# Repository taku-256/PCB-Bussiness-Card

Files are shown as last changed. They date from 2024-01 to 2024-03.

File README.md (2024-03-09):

# WS2812B with PIC Microcontroller
created by taku-256 @taku_8bits

PICマイコンでNeoPixcelライブラリなしでWS2812Bの制御をする基板です。
高専ロボコン2023用に作成したものを改良しました。

2024年3月現在、部内ロボコンの回路、制御のワンオペ作業に追われているためDCDCを実装した際の動作確認ができていません。
それを除いた動作は確認しておりますので、ぜひ実際に実装して遊んでいただけると嬉しいです。

使用したマイコンはPIC18F26Q84で10MHzの水晶発振子をつけて動かしています。
この基板はこのマイコンの評価基板としても使えるようにピンヘッダーをつけられるようになっているのでPICマイコンに触れてみたい人は是非使ってみてください。

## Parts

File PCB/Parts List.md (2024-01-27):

# Parts List

| Part | Value or name(URL : 秋月電商/千石電商)|
|:----|----:|
| C1,2 | [100μF](https://akizukidenshi.com/catalog/g/g117877/) |
| C3 | [0.1μF](https://akizukidenshi.com/catalog/g/g100090/) |
| C4,5 | [33pF](https://akizukidenshi.com/catalog/g/g105109/) |
| C6,7 | [0.1μF(1608)](https://akizukidenshi.com/catalog/g/g113374/) |
| R1 | [330Ω(3216)](https://www.sengoku.co.jp/mod/sgk_cart/detail.php?code=EEHD-0CPK) |
| R2 | [1kΩ(2012)](https://akizukidenshi.com/catalog/g/g111796/) |
| R3,4 | [10kΩ(2012)](https://akizukidenshi.com/catalog/g/g111797/) |
| R5 | [200Ω(3216)](https://www.sengoku.co.jp/mod/sgk_cart/detail.php?code=EEHD-0ECC) |
| D1 | [LED(0603)](https://akizukidenshi.com/catalog/g/g109640/) |
| LED1,2 | [WS2812B](https://akizukidenshi.com/catalog/g/g107915/) |
| S1,2 | [トグルスイッチ](https://akizukidenshi.com/catalog/g/g100300/) |
| S3 | [タクトスイッチ](https://akizukidenshi.com/catalog/g/g103648/) |
| J1 | [Type-Cコネクタ](https://akizukidenshi.com/catalog/g/g116895/) |
| JP1,2 | [ピンソケット 1×42](https://akizukidenshi.com/catalog/g/g105779/) |
| JP3,4 | [NHコネクタ 3P L字](https://akizukidenshi.com/catalog/g/g114418/) |
| PICKIT | [L字ピンヘッダ 1×10](https://akizukidenshi.com/catalog/g/g106362/) |
| Q1 | [10MHz](https://akizukidenshi.com/catalog/g/g108668/) |
| PS1 | [OKL-T_6-W12N-C](https://akizukidenshi.com/catalog/g/g106187/) |
| U$1 | [VHコネクタ 2P](https://akizukidenshi.com/catalog/g/g112815/) |
| U$2 | [PIC18F26Q84](https://akizukidenshi.com/catalog/g/g116448/) |

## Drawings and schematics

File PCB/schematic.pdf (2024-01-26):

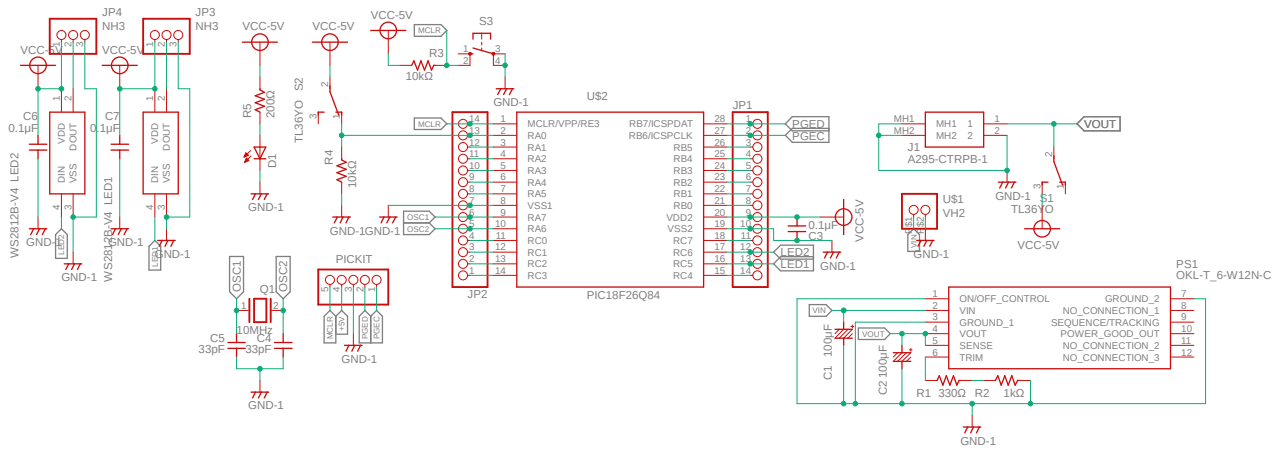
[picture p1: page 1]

13 | | RA0 2
12 | | RA1 3

10
11 12

VIN 2
GROUND_1 3
VOUT 4 SENSE 5

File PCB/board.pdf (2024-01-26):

## MODEPOWER

# taku_256

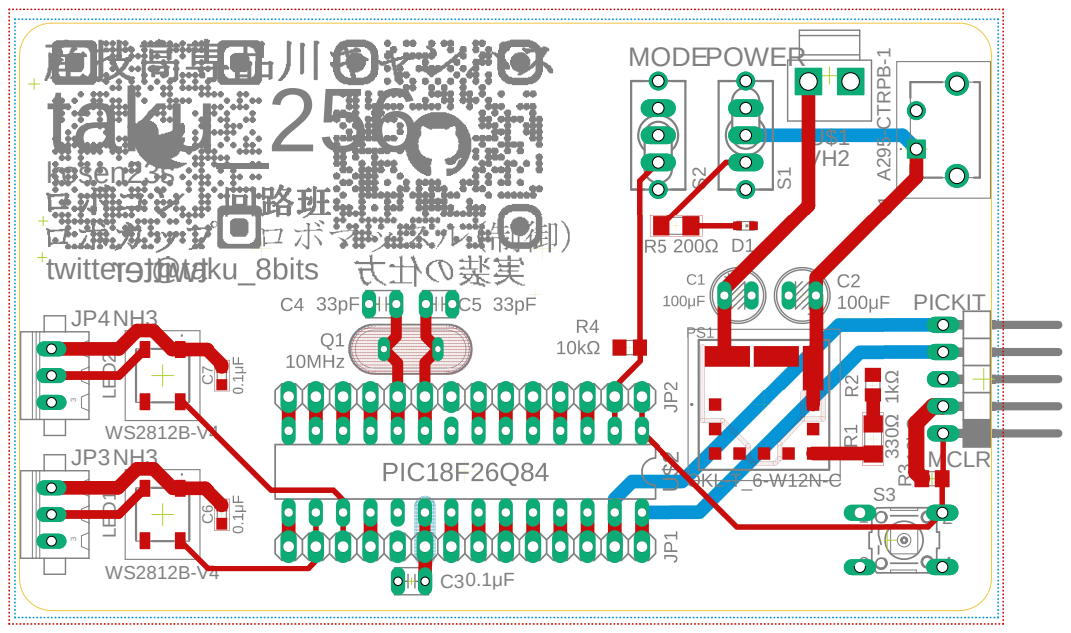
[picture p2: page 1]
kosen23s; twitter : @taku_8bits; MCLR; J1 A²⁹⁵⁻CTRPB⁻¹; PICKIT R³¹⁰k; S2 LED2; WS2812B-V4 LED¹

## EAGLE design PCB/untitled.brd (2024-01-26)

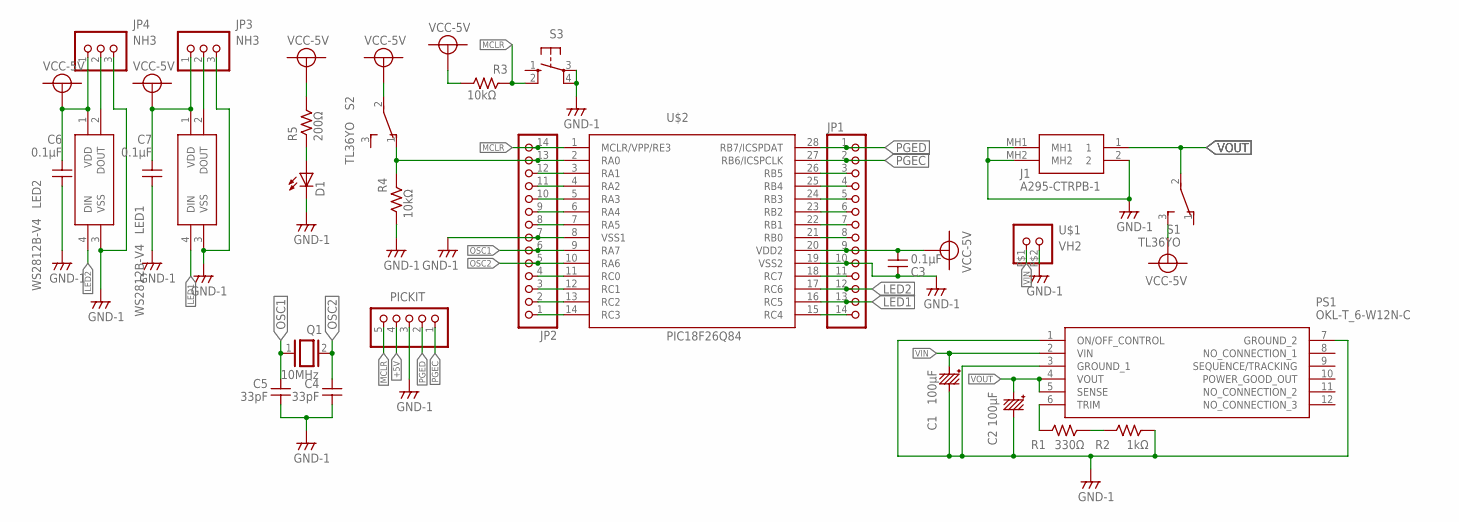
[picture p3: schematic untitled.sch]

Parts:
C1, C2: 100μF; CC:3
C3: 0.1μF; C:1
C4, C5: 33pF; C:1
C6, C7: 0.1μF; C1608
D1: LED""""; CHIPLED_0603
J1: A295-CTRPB-1; A295CTRPB1
JP1, JP2: PINHD-1X14; 1X14
JP3, JP4: NH3
LED1, LED2: WS2812B-V4; WS2812BV4
PICKIT: PINHD-1X5/90; 1X05/90
PS1: OKL-T_6-W12N-C; OKLT6W12NC
Q1: 10MHz; QS
R1: 330Ω; C3216
R2: 1kΩ; 2012
R3, R4: 10kΩ; 2012
R5: 200Ω; C3216
S1, S2: TL36YO; TL3XYO
S3: 10-XX; B3F-10XX
U$1: VH2
U$2: PIC18F26Q84; DIL28-3

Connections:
+5V: C3.P$1, C6.2, C7.2, JP1.9, JP3.1, JP4.1, LED1.1 (VDD), LED2.1 (VDD), PICKIT.4, R3.1, R5.2, S1.3 (S), S2.2, U$2.20 (VDD2)
GND: C1.- (P$2-), C2.- (P$2-), C3.P$2, C4.P$1, C5.P$1, C6.1, C7.1, D1.C, J1.2, J1.MH1, J1.MH2, JP1.10, JP2.7, JP3.3, JP4.3, LED1.3 (VSS), LED2.3 (VSS), PICKIT.3, PS1.1 (ON/OFF_CONTROL), PS1.3 (GROUND_1), PS1.7 (GROUND_2), R2.2, R4.1, S3.3, S3.4 (P1), U$1.P$2, U$2.8 (VSS1), U$2.19 (VSS2)
LED1: JP1.13, LED1.4 (DIN), U$2.16 (RC5)
LED2: JP1.12, LED2.4 (DIN), U$2.17 (RC6)
MCLR: JP2.14, PICKIT.5, R3.2, S3.2 (S1), U$2.1 (MCLR/VPP/RE3)
unnamed: JP4.2, LED2.2 (DOUT)
unnamed: JP2.13, R4.2, S2.1 (O), U$2.2 (RA0)
unnamed: JP2.12, U$2.3 (RA1)
unnamed: JP2.11, U$2.4 (RA2)
unnamed: JP2.10, U$2.5 (RA3)
unnamed: JP2.9, U$2.6 (RA4)
unnamed: JP2.8, U$2.7 (RA5)
unnamed: PS1.6 (TRIM), R1.1
unnamed: R1.2, R2.1
unnamed: JP2.4, U$2.11 (RC0)
unnamed: JP2.3, U$2.12 (RC1)
unnamed: JP2.2, U$2.13 (RC2)
unnamed: JP2.1, U$2.14 (RC3)
unnamed: D1.A, R5.1
unnamed: JP1.8, U$2.21 (RB0)
unnamed: JP3.2, LED1.2 (DOUT)
unnamed: JP1.7, U$2.22 (RB1)
unnamed: JP1.6, U$2.23 (RB2)
unnamed: JP1.5, U$2.24 (RB3)
unnamed: JP1.4, U$2.25 (RB4)
unnamed: JP1.3, U$2.26 (RB5)
unnamed: JP1.11, U$2.18 (RC7)
unnamed: JP1.14, U$2.15 (RC4)
OSC1: C5.P$2, JP2.6, Q1.1, U$2.9 (RA7)
OSC2: C4.P$2, JP2.5, Q1.2, U$2.10 (RA6)
PGEC: JP1.2, PICKIT.1, U$2.27 (RB6/ICSPCLK)
PGED: JP1.1, PICKIT.2, U$2.28 (RB7/ICSPDAT)
VIN: C1.+ (P$1+), PS1.2 (VIN), U$1.P$1
VOUT: C2.+ (P$1+), J1.1, PS1.4 (VOUT), PS1.5 (SENSE), S1.2

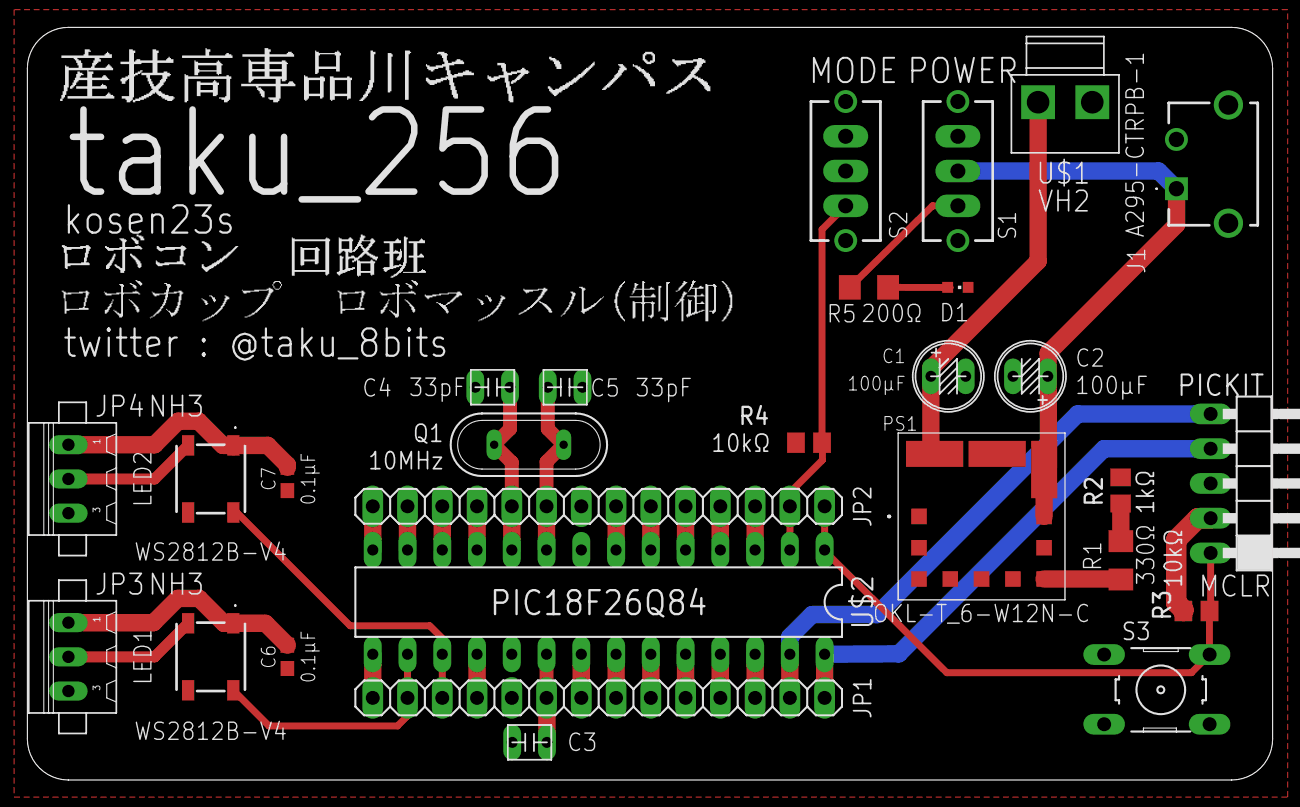
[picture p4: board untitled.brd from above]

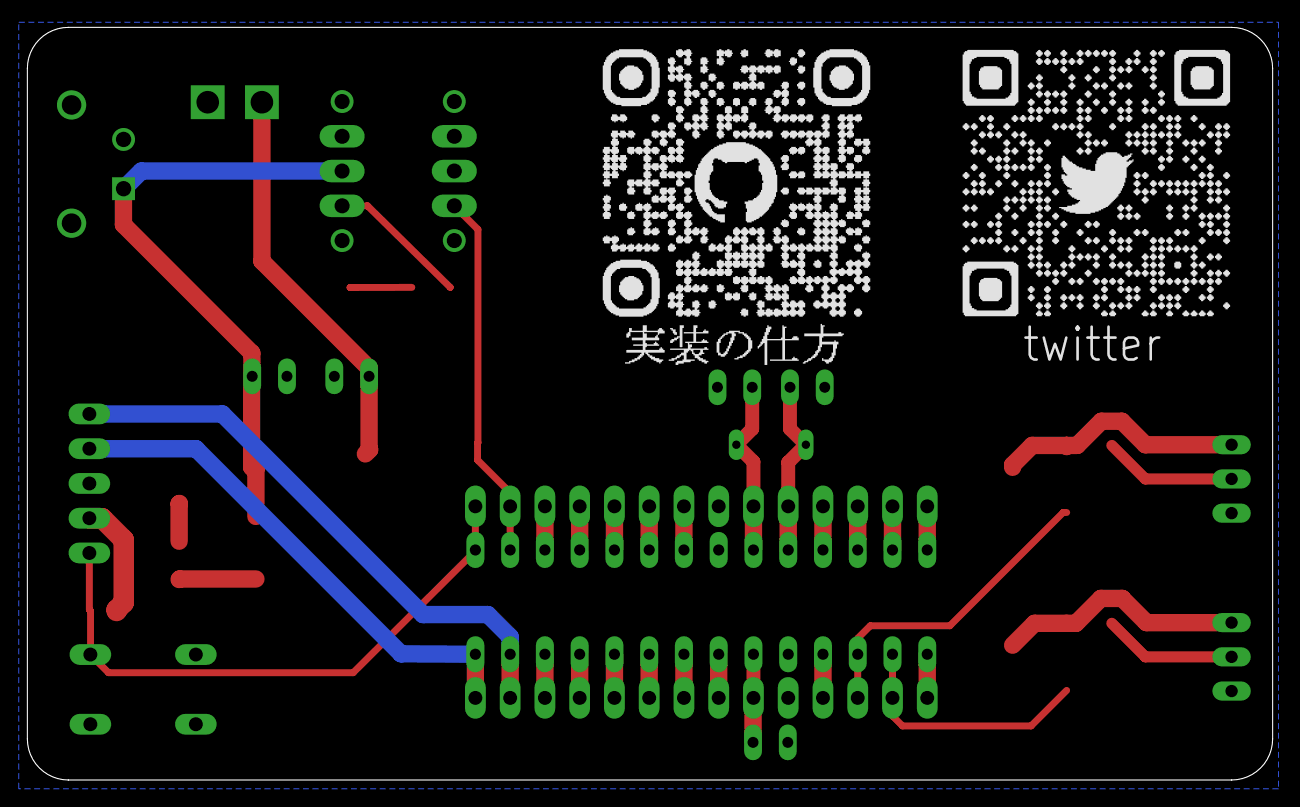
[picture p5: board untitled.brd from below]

Board: 2 copper layers, 91.0 x 55.0 mm, 34 parts (3 on the bottom side), 34 nets.

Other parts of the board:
U$10: HOWTOMAKE
U$11: TMCIT
U$13: TWITTER
U$14: MEISHI-GIT-QR
U$15: ROBOCON
U$16: ROBOMUSCLE

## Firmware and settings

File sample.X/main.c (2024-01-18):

/**
  Generated Main Source File

  Company:
    Microchip Technology Inc.

  File Name:
    main.c

  Summary:
    This is the main file generated using PIC10 / PIC12 / PIC16 / PIC18 MCUs

  Description:
    This header file provides implementations for driver APIs for all modules selected in the GUI.
    Generation Information :
        Product Revision  :  PIC10 / PIC12 / PIC16 / PIC18 MCUs - 1.81.8
        Device            :  PIC18F26Q84
        Driver Version    :  2.00
*/

/*
    (c) 2018 Microchip Technology Inc. and its subsidiaries. 
    
    Subject to your compliance with these terms, you may use Microchip software and any 
    derivatives exclusively with Microchip products. It is your responsibility to comply with third party 
    license terms applicable to your use of third party software (including open source software) that 
    may accompany Microchip software.
    
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
    IN NO EVENT WILL MICROCHIP BE LIABLE FOR ANY INDIRECT, SPECIAL, PUNITIVE, 
    INCIDENTAL OR CONSEQUENTIAL LOSS, DAMAGE, COST OR EXPENSE OF ANY KIND 
    WHATSOEVER RELATED TO THE SOFTWARE, HOWEVER CAUSED, EVEN IF MICROCHIP 
    HAS BEEN ADVISED OF THE POSSIBILITY OR THE DAMAGES ARE FORESEEABLE. TO 
    THE FULLEST EXTENT ALLOWED BY LAW, MICROCHIP'S TOTAL LIABILITY ON ALL 
    CLAIMS IN ANY WAY RELATED TO THIS SOFTWARE WILL NOT EXCEED THE AMOUNT 
    OF FEES, IF ANY, THAT YOU HAVE PAID DIRECTLY TO MICROCHIP FOR THIS 
    SOFTWARE.
*/

#include "mcc_generated_files/mcc.h"
        
struct bits {
    unsigned char b1 : 1;
    unsigned char b2 : 1;
    unsigned char b3 : 1;
    unsigned char b4 : 1;
    unsigned char b5 : 1;
    unsigned char b6 : 1;
    unsigned char b7 : 1;
    unsigned char b8 : 1;
};
        
typedef union{
    uint8_t chr;
    struct bits b;
}iro;
        
iro r,g,b;
        
int RGB[3][160],MODE,MOVE;
        
int nanntoka;
        
int port1_zero(){
    LATCbits.LATC6 = 1;
    LATCbits.LATC6 = 1;
    LATCbits.LATC6 = 1;
    LATCbits.LATC6 = 0;
    LATCbits.LATC6 = 0;
    LATCbits.LATC6 = 0;
    LATCbits.LATC6 = 0;
    LATCbits.LATC6 = 0;
    LATCbits.LATC6 = 0;
    LATCbits.LATC6 = 0;
}
        
int port1_one(){//400ns
    LATCbits.LATC6 = 1;
    LATCbits.LATC6 = 1;
    LATCbits.LATC6 = 1;
    LATCbits.LATC6 = 1;
    LATCbits.LATC6 = 1;
    LATCbits.LATC6 = 1;
    LATCbits.LATC6 = 1;
    LATCbits.LATC6 = 0;
    LATCbits.LATC6 = 0;
    LATCbits.LATC6 = 0;
    LATCbits.LATC6 = 0;
    LATCbits.LATC6 = 0;
    LATCbits.LATC6 = 0;
    LATCbits.LATC6 = 0;
}
        
int port2_zero(){
    LATCbits.LATC5 = 1;
    LATCbits.LATC5 = 1;
    LATCbits.LATC5 = 1;
    LATCbits.LATC5 = 0;
    LATCbits.LATC5 = 0;
    LATCbits.LATC5 = 0;
    LATCbits.LATC5 = 0;
    LATCbits.LATC5 = 0;
    LATCbits.LATC5 = 0;
    LATCbits.LATC5 = 0;
}
        
int port2_one(){//400ns
    LATCbits.LATC5 = 1;
    LATCbits.LATC5 = 1;
    LATCbits.LATC5 = 1;
    LATCbits.LATC5 = 1;
    LATCbits.LATC5 = 1;
    LATCbits.LATC5 = 1;
    LATCbits.LATC5 = 1;
    LATCbits.LATC5 = 0;
    LATCbits.LATC5 = 0;
    LATCbits.LATC5 = 0;
    LATCbits.LATC5 = 0;
    LATCbits.LATC5 = 0;
    LATCbits.LATC5 = 0;
    LATCbits.LATC5 = 0;
}
        
int (*port1_send1bit[2])() = {port1_zero,port1_one};
        
int (*port2_send1bit[2])() = {port2_zero,port2_one};
        
int port1_send3byte(int R,int G,int B){
    g.chr = G;r.chr = R;b.chr = B;
    
    port1_send1bit[g.b.b1]();
    port1_send1bit[g.b.b2]();
    port1_send1bit[g.b.b3]();
    port1_send1bit[g.b.b4]();
    port1_send1bit[g.b.b5]();
    port1_send1bit[g.b.b6]();
    port1_send1bit[g.b.b7]();
    port1_send1bit[g.b.b8]();
    port1_send1bit[r.b.b1]();
    port1_send1bit[r.b.b2]();
    port1_send1bit[r.b.b3]();
    port1_send1bit[r.b.b4]();
    port1_send1bit[r.b.b5]();
    port1_send1bit[r.b.b6]();
    port1_send1bit[r.b.b7]();
    port1_send1bit[r.b.b8]();
    port1_send1bit[b.b.b1]();
    port1_send1bit[b.b.b2]();
    port1_send1bit[b.b.b3]();
    port1_send1bit[b.b.b4]();
    port1_send1bit[b.b.b5]();
    port1_send1bit[b.b.b6]();
    port1_send1bit[b.b.b7]();
    port1_send1bit[b.b.b8]();
}
        
int port2_send3byte(int R,int G,int B){
    g.chr = G;r.chr = R;b.chr = B;
    
    port2_send1bit[g.b.b1]();
    port2_send1bit[g.b.b2]();
    port2_send1bit[g.b.b3]();
    port2_send1bit[g.b.b4]();
    port2_send1bit[g.b.b5]();
    port2_send1bit[g.b.b6]();
    port2_send1bit[g.b.b7]();
    port2_send1bit[g.b.b8]();
    port2_send1bit[r.b.b1]();
    port2_send1bit[r.b.b2]();
    port2_send1bit[r.b.b3]();
    port2_send1bit[r.b.b4]();
    port2_send1bit[r.b.b5]();
    port2_send1bit[r.b.b6]();
    port2_send1bit[r.b.b7]();
    port2_send1bit[r.b.b8]();
    port2_send1bit[b.b.b1]();
    port2_send1bit[b.b.b2]();
    port2_send1bit[b.b.b3]();
    port2_send1bit[b.b.b4]();
    port2_send1bit[b.b.b5]();
    port2_send1bit[b.b.b6]();
    port2_send1bit[b.b.b7]();
    port2_send1bit[b.b.b8]();
}
        
int Red(){
    while(1){
        if(MODEIN_PORT != nanntoka){break;}
        
        for(int i = 0;i < 10;i++){
            port1_send3byte(255,0,0);
            port1_send3byte(255,0,0);
            port1_send3byte(255,0,0);
            port1_send3byte(255,255,0);
            port1_send3byte(255,255,0);
            port1_send3byte(255,255,0);
        }
        
        for(int i = 0;i < 10;i++){
            port2_send3byte(255,255,0);
            port2_send3byte(255,255,0);
            port2_send3byte(255,255,0);
            port2_send3byte(255,0,0);
            port2_send3byte(255,0,0);
            port2_send3byte(255,0,0);
        }
        
        __delay_ms(150);
        
        if(MODEIN_PORT != nanntoka){break;}
        
        for(int i = 0;i < 10;i++){
            port1_send3byte(255,255,0);
            port1_send3byte(255,255,0);
            port1_send3byte(255,255,0);
            port1_send3byte(255,0,0);
            port1_send3byte(255,0,0);
            port1_send3byte(255,0,0);
        }
        
        for(int i = 0;i < 10;i++){
            port2_send3byte(255,0,0);
            port2_send3byte(255,0,0);
            port2_send3byte(255,0,0);
            port2_send3byte(255,255,0);
            port2_send3byte(255,255,0);
            port2_send3byte(255,255,0);
        }
        
        __delay_ms(150);
        
    }
}
        
int Blue(){
    while(1){
        if(MODEIN_PORT != nanntoka){break;}
        
        for(int i = 0;i < 35;i++){
            port1_send3byte(0,0,255);
            port1_send3byte(0,0,255);
            port1_send3byte(0,0,255);
            port1_send3byte(186,255,255);
            port1_send3byte(186,255,255);
            port1_send3byte(186,255,255);
        }
        
        for(int i = 0;i < 10;i++){
            port2_send3byte(186,255,255);
            port2_send3byte(186,255,255);
            port2_send3byte(186,255,255);
            port2_send3byte(0,0,255);
            port2_send3byte(0,0,255);
            port2_send3byte(0,0,255);
        }
        
        __delay_ms(150);
        
        if(MODEIN_PORT != nanntoka){break;}
        
        for(int i = 0;i < 10;i++){
            port1_send3byte(186,255,255);
            port1_send3byte(186,255,255);
            port1_send3byte(186,255,255);
            port1_send3byte(0,0,255);     
            port1_send3byte(0,0,255);
            port1_send3byte(0,0,255);     
        }
        
        for(int i = 0;i < 10;i++){
            port2_send3byte(0,0,255);
            port2_send3byte(0,0,255);
            port2_send3byte(0,0,255);
            port2_send3byte(186,255,255);
            port2_send3byte(186,255,255);
            port2_send3byte(186,255,255);
        }
        
        __delay_ms(150);
        
    }
}

void Gaming(){
    for(int i = 0;i < 10;i++){
        port1_send3byte(255,0,0);
        port1_send3byte(255,165,0);
        port1_send3byte(255,255,0);
        port1_send3byte(0,255,0);
        port1_send3byte(0,255,255);
        port1_send3byte(0,0,255);
        port1_send3byte(255,0,255);
    }
    
    for(int i = 0;i < 10;i++){
        port2_send3byte(255,0,0);
        port2_send3byte(255,165,0);
        port2_send3byte(255,255,0);
        port2_send3byte(0,255,0);
        port2_send3byte(0,255,255);
        port2_send3byte(0,0,255);
        port2_send3byte(255,0,255);
    }
    
    __delay_ms(50);
    
    for(int i = 0;i < 10;i++){
        port1_send3byte(255,165,0);
        port1_send3byte(255,255,0);
        port1_send3byte(0,255,0);
        port1_send3byte(0,255,255);
        port1_send3byte(0,0,255);
        port1_send3byte(255,0,255);
        port1_send3byte(255,0,0);
    }
    
    for(int i = 0;i < 10;i++){
        port2_send3byte(255,165,0);
        port2_send3byte(255,255,0);
        port2_send3byte(0,255,0);
        port2_send3byte(0,255,255);
        port2_send3byte(0,0,255);
        port2_send3byte(255,0,255);
        port2_send3byte(255,0,0);
    }
    
    __delay_ms(50);
    
    for(int i = 0;i < 10;i++){
        port1_send3byte(255,255,0);
        port1_send3byte(0,255,0);
        port1_send3byte(0,255,255);
        port1_send3byte(0,0,255);
        port1_send3byte(255,0,255);
        port1_send3byte(255,0,0);
        port1_send3byte(255,165,0);
    }
    
    for(int i = 0;i < 10;i++){
        port2_send3byte(255,255,0);
        port2_send3byte(0,255,0);
        port2_send3byte(0,255,255);
        port2_send3byte(0,0,255);
        port2_send3byte(255,0,255);
        port2_send3byte(255,0,0);
        port2_send3byte(255,165,0);
    }
    
    __delay_ms(50);
    
    for(int i = 0;i < 10;i++){
        port1_send3byte(0,255,0);
        port1_send3byte(0,255,255);
        port1_send3byte(0,0,255);
        port1_send3byte(255,0,255);
        port1_send3byte(255,0,0);
        port1_send3byte(255,165,0);
        port1_send3byte(255,255,0);
    }
    
    for(int i = 0;i < 10;i++){
        port2_send3byte(0,255,0);
        port2_send3byte(0,255,255);
        port2_send3byte(0,0,255);
        port2_send3byte(255,0,255);
        port2_send3byte(255,0,0);
        port2_send3byte(255,165,0);
        port2_send3byte(255,255,0);
    }
    
    __delay_ms(50);
    
    for(int i = 0;i < 10;i++){
        port1_send3byte(0,255,255);
        port1_send3byte(0,0,255);
        port1_send3byte(255,0,255);
        port1_send3byte(255,0,0);
        port1_send3byte(255,165,0);
        port1_send3byte(255,255,0);
        port1_send3byte(0,255,0);
    }
    
    for(int i = 0;i < 10;i++){
        port2_send3byte(0,255,255);
        port2_send3byte(0,0,255);
        port2_send3byte(255,0,255);
        port2_send3byte(255,0,0);
        port2_send3byte(255,165,0);
        port2_send3byte(255,255,0);
        port2_send3byte(0,255,0);
    }
    
    __delay_ms(50);
    
    for(int i = 0;i < 10;i++){
        port1_send3byte(0,0,255);
        port1_send3byte(255,0,255);
        port1_send3byte(255,0,0);
        port1_send3byte(255,165,0);
        port1_send3byte(255,255,0);
        port1_send3byte(0,255,0);
        port1_send3byte(0,255,255);
    }
    
    for(int i = 0;i < 10;i++){
        port2_send3byte(0,0,255);
        port2_send3byte(255,0,255);
        port2_send3byte(255,0,0);
        port2_send3byte(255,165,0);
        port2_send3byte(255,255,0);
        port2_send3byte(0,255,0);
        port2_send3byte(0,255,255);
    }
    
    __delay_ms(50);
    
    for(int i = 0;i < 10;i++){
        port1_send3byte(255,0,255);
        port1_send3byte(255,0,0);
        port1_send3byte(255,165,0);
        port1_send3byte(255,255,0);
        port1_send3byte(0,255,0);
        port1_send3byte(0,255,255);
        port1_send3byte(0,0,255);
    }
    
    for(int i = 0;i < 10;i++){
        port2_send3byte(255,0,255);
        port2_send3byte(255,0,0);
        port2_send3byte(255,165,0);
        port2_send3byte(255,255,0);
        port2_send3byte(0,255,0);
        port2_send3byte(0,255,255);
        port2_send3byte(0,0,255);
    }
    
    __delay_ms(50);
}

void main(void){
    // Initialize the device
    SYSTEM_Initialize();

    // If using interrupts in PIC18 High/Low Priority Mode you need to enable the Global High and Low Interrupts
    // If using interrupts in PIC Mid-Range Compatibility Mode you need to enable the Global Interrupts
    // Use the following macros to:

    // Enable the Global Interrupts
//    INTERRUPT_GlobalInterruptEnable();
    
    TRISCbits.TRISC4 = 0;
    TRISCbits.TRISC6 = 0;
    TRISCbits.TRISC5 = 0;
    TRISAbits.TRISA0 = 1;
    
    nanntoka = PORTAbits.RA0;
 
    while (1){
        
        // Add your application code
        
        while(nanntoka == PORTAbits.RA0){Gaming();}
        nanntoka = PORTAbits.RA0;
        
        while(nanntoka == PORTAbits.RA0){Red();}
        nanntoka = PORTAbits.RA0;
        
        while(nanntoka == PORTAbits.RA0){Blue();}
        nanntoka = PORTAbits.RA0;

    }
}
/**
 End of File
*/

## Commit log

2024-01-18 サンプルプログラムのアップロード
2024-01-26 基板の設計データの公開
    [untitled.brd, untitled.sch]
2024-01-26 回路図等のPDF版でのアップロード
